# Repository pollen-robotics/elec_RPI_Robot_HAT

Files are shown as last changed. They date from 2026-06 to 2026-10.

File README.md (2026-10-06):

# "RPI_Robot_HAT" Electronic Board

> "RPI_Robot_HAT" is a raspberry pi HAT designed for small/medium size robots. It has an IMU, Dynamixel connectors and audio. Its size fits a Raspberry PI zero.

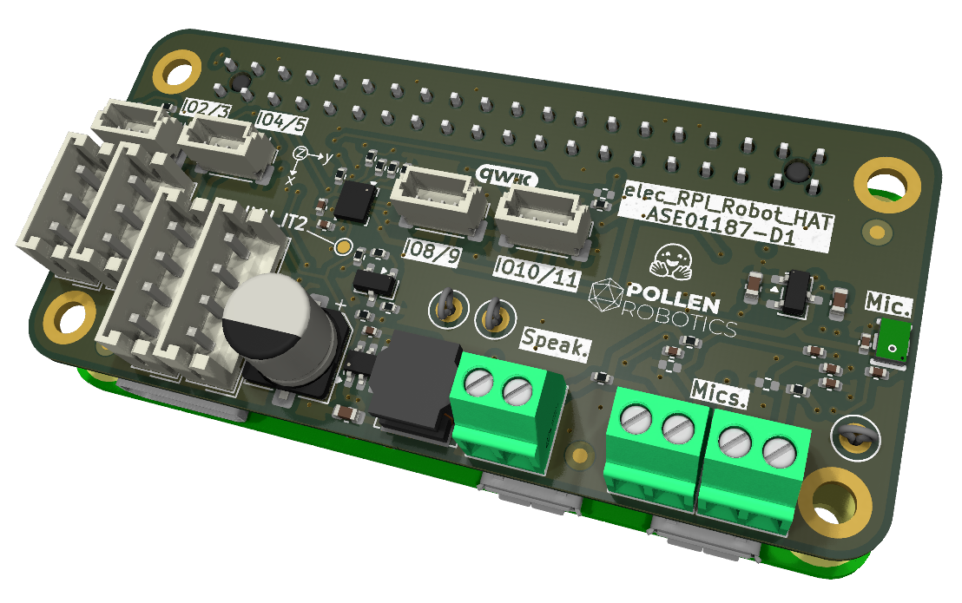
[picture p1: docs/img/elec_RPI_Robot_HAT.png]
3d view


The RPI_Robot_HAT gathers:

- **IMU** over I2C + data fusion
- **Dynamixel motor communication**: both TTL and 485 to drive Dynamixel/Feetech motor (requires cable adaptation)
- **in/out audio device** with an integrated mems microphone. Wago connectors allows connection of loudspeaker and extra microphone.
- **expension Qwiic connectors**, 1 mm/3V3. Please refer to the schematic for knowing which can be use on you raspberry pi.

The RPI_Robot_HAT can be power from 5 to 28V. It is designed to use of the motor connector as an power input.

## Releases
| Release | Date | Designer | Check  | Comments |
|---|---|---|---|---|
| A1 | 06/03/2026 | EB | SN | Initial drawing |
| B1 | 06/05/2026 | EB | SN |[fixed] Acc. is at 0x19 I2C address<br />[fixed] Soft reset of the audio DAC<br />[fixed] Ideal diode<br />[fixed] Know position of IMU<br />[update] Dynamixel_dir is based on Tx<br />[added] IMU can be disconnected<br />[added] IMU_IT is cabled<br />[added] Access to I2C0<br />[added] Switch off detection|
| C1 | 08/07/2026 | EB | SN | [fix] 3V3 on IO10/11<br />[fix] MOS direction of Ideal diode<br />[update] I2C3 is by default instead of reserved I2C|
| D1 | 06/10/2026 | EB | Claude | [update] IMU is now LSM6DSV16XTR<br />[update] RS485 Driver<br /> [update] screwable terminals for audio|

## Basically
 - Designed with KiCAD 9.

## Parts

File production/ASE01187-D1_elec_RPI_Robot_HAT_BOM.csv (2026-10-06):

Designator | Footprint | Quantity | Value | LCSC Part #
C1, C10, C2, C27, C29, C3, C31, C33, C35, C4, C40, C41, C42, C43, C6 | 0402 | 15 | 1u | C52923
C11, C14, C15, C16, C17, C18, C26, C28, C30, C32, C36, C38 | 0402 | 12 | 100n | C307331
C12, C13, C37, C5, C7 | 0603 | 5 | 10u | C1691
C19 | CP_Elec_6.3x7.7 | 1 | 10u 63V | C72488
C20 | 0402 | 1 | 100n 50V | C307331
C21, C22 | 0603 | 2 | 22u 6V3 | C84419
C23, C24, C39 | 0402 | 3 | 100n 6V3 | C1525
C25 | 0402 | 1 | DNP-100n
C34, C44 | 0402 | 2 | 10n | C15195
C45 | 0805 | 1 | 10u 35V | C33546007
C8, C9 | 0402 | 2 | 220n | C71693
D1 | SOT-323_SC-70 | 1 | BAT54W | C78606
D2 | D_SOD-123 | 1 | 3V3 Zener Diode | C19077392
D4 | D_SOD-323 | 1 | 5V1 | C151348
FB1 | 0402 | 1 | 1.3A 600R@100MHz | C76884
FB2, FB3 | 0402 | 2 | 2A - 120R@100MHz | C88970
G1 | Logo_qwiic_5mm | 1 | qwiic_Logo
H2 | Logo_HF_2025 | 1 | Logo HF 2025
J1, J2, J9 | CONN-TH_DB125-2.54-2P-GN | 3 | Screw term. | C918120
J11, J3 | JST_EH_B4B-EH-A_1x04_P2.50mm_Vertical | 2 | Dynamixel-4 | C160258
J13, J14 | JST_EH_B3B-EH-A_1x03_P2.50mm_Vertical | 2 | Dynamixel-3 | C160259
J4 | PinHeader_2x20_P2.54mm_Vertical_with_rasp_HAT_zero_SMD_connector | 1 | Female Header 2x20 SMD | C2685112
J5, J6, J7, J8 | JST_SH_BM04B-SRSS-TB_1x04-1MP_P1.00mm_Vertical | 4 | JST SH | C160390
L4 | L_Bourns_SRN6045TA | 1 | 6,8u 2A | C57254
MK1 | MIC-SMD_4P-L2.8-W1.9-P1.84-TL | 1 | Microphone_MEMS | C7587901
Q1 | SOT-23 | 1 | MMBT3906 | C727128
Q2 | TSOT-23 | 1 | N-Channel 5A | C22469448
R1, R12, R13, R2, R20, R21, R24, R26, R27, R29, R31, R32, R34, R35, R38, R39, R6 | 0402 | 17 | 10k | C25744
R10, R11 | 0402 | 2 | DNP-10k
R14, R15, R18, R19, R25, R3, R30, R4, R40, R5, R7, R9 | 0402 | 12 | 0R | C17168
R16, R17, R41 | 0402 | 3 | DNP-0R
R22, R23 | 0402 | 2 | 4k7 | C105871
R28 | 0402 | 1 | 20k | C25765
R33 | 0402 | 1 | 150R | C2909321
R36, R37 | 0402 | 2 | DNP-1M
R42 | 0402 | 1 | 1k | C105637
R8 | 0402 | 1 | 100R | C2906860
TH1 | 0603 | 1 | 100R thermistor | C913703
TP2, TP3, TP4 | TestPoint_Loop_D2.50mm_Drill1.0mm_LowProfile | 3 | TestPoint
TP5 | TestPoint_Pad_D1.0mm | 1 | TestPoint
U1 | SOIC-16_3.9x9.9mm_P1.27mm | 1 | PAM8406D | C86270
U10 | TSOT-23-6 | 1 | LM5050-1 | C473393
U12 | LGA-14_3x2.5mm_P0.5mm_LayoutBorder3x4y | 1 | LSM6DSV16XTR | C5267406
U2 | VQFN-32-1EP_5x5mm_P0.5mm_EP3.5x3.5mm | 1 | TLV320AIC3104IRHBR | C181753
U3 | SOT-23-3 | 1 | XC6206P182MR | C347373
U4 | TDFN-8_L3.0-W2.0-P0.50-BL-EP | 1 | DNP-CAT24C32HU4
U5 | SOT-23-5 | 1 | 74LVC1G08 | C7666
U6 | SOT-23-5 | 1 | SN74LVC1G125DBV | C23654
U7 | SOT-23-5 | 1 | SN74LVC1G126DBVR | C7834
U8 | DFN-8-1EP_3x3mm_P0.65mm_EP1.2x2.15mm | 1 | GM3088ENA | C49423279
U9 | TSOT-23-6 | 1 | AP63205 | C2071056
Y1 | Oscillator_SMD_Abracon_ASDMB-4Pin_2.5x2.0mm | 1 | 12 MHz | C7425459

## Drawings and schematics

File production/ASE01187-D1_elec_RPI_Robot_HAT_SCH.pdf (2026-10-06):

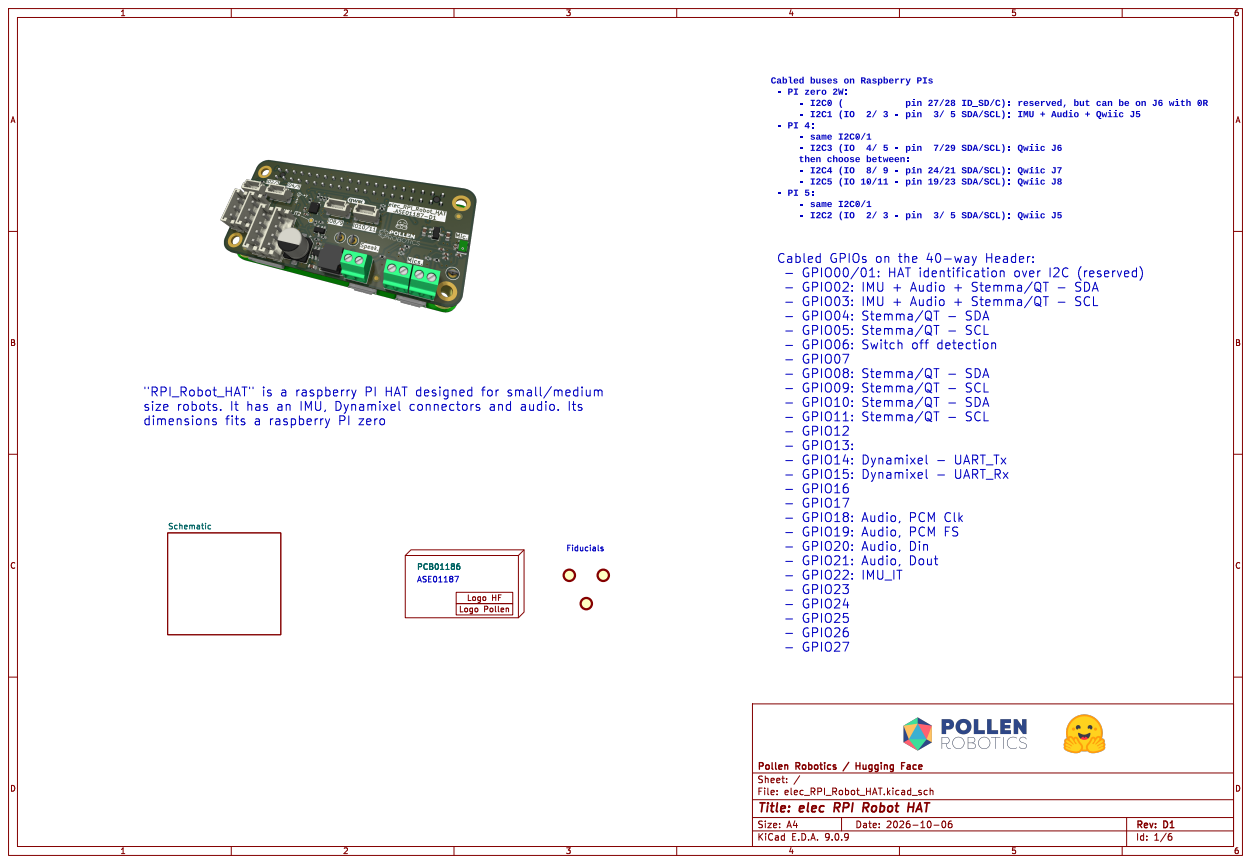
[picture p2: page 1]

Cabled buses on Raspberry PIs
- PI zero 2W:
- same I2C0/1
then choose between:
- I2C5 (IO 10/11 - pin 19/23 SDA/SCL): Qwiic J8

Id: 1/6 Title: elec RPI Robot HAT

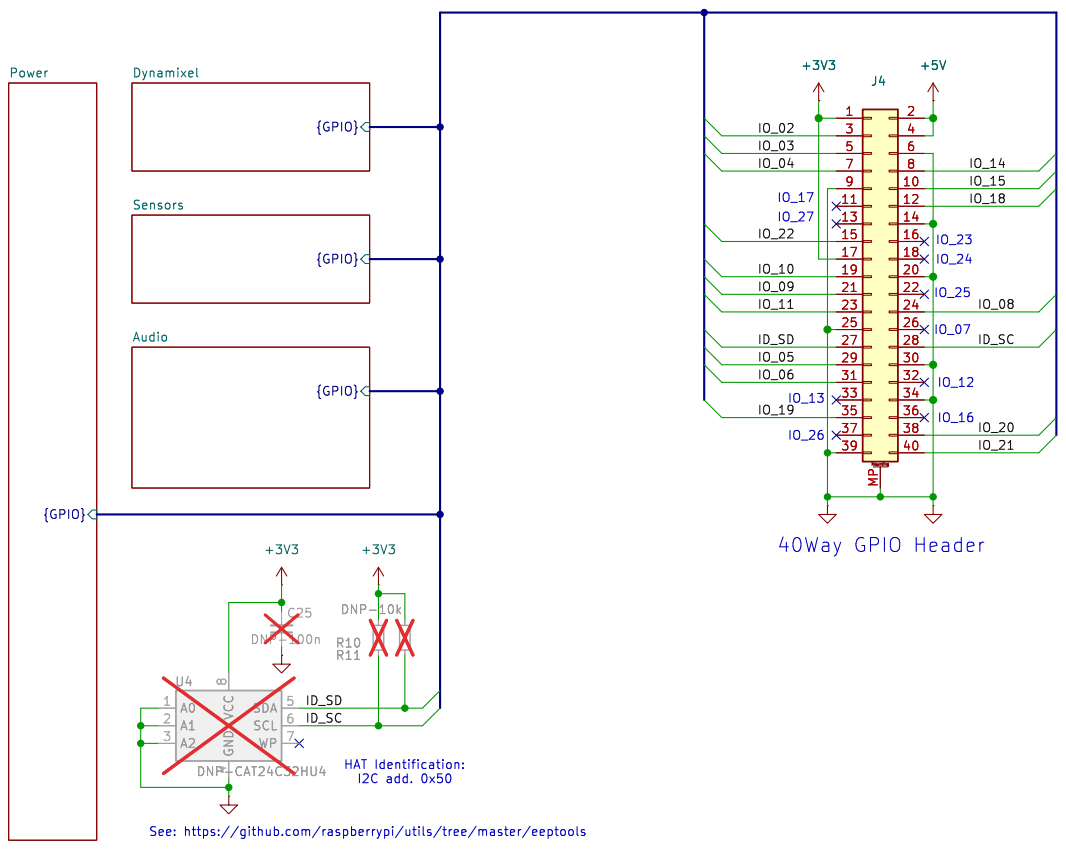
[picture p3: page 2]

I2C add. 0x50 See: https://github.com/raspberrypi/utils/tree/master/eeptools

Id: 2/6 Title: elec RPI Robot HAT

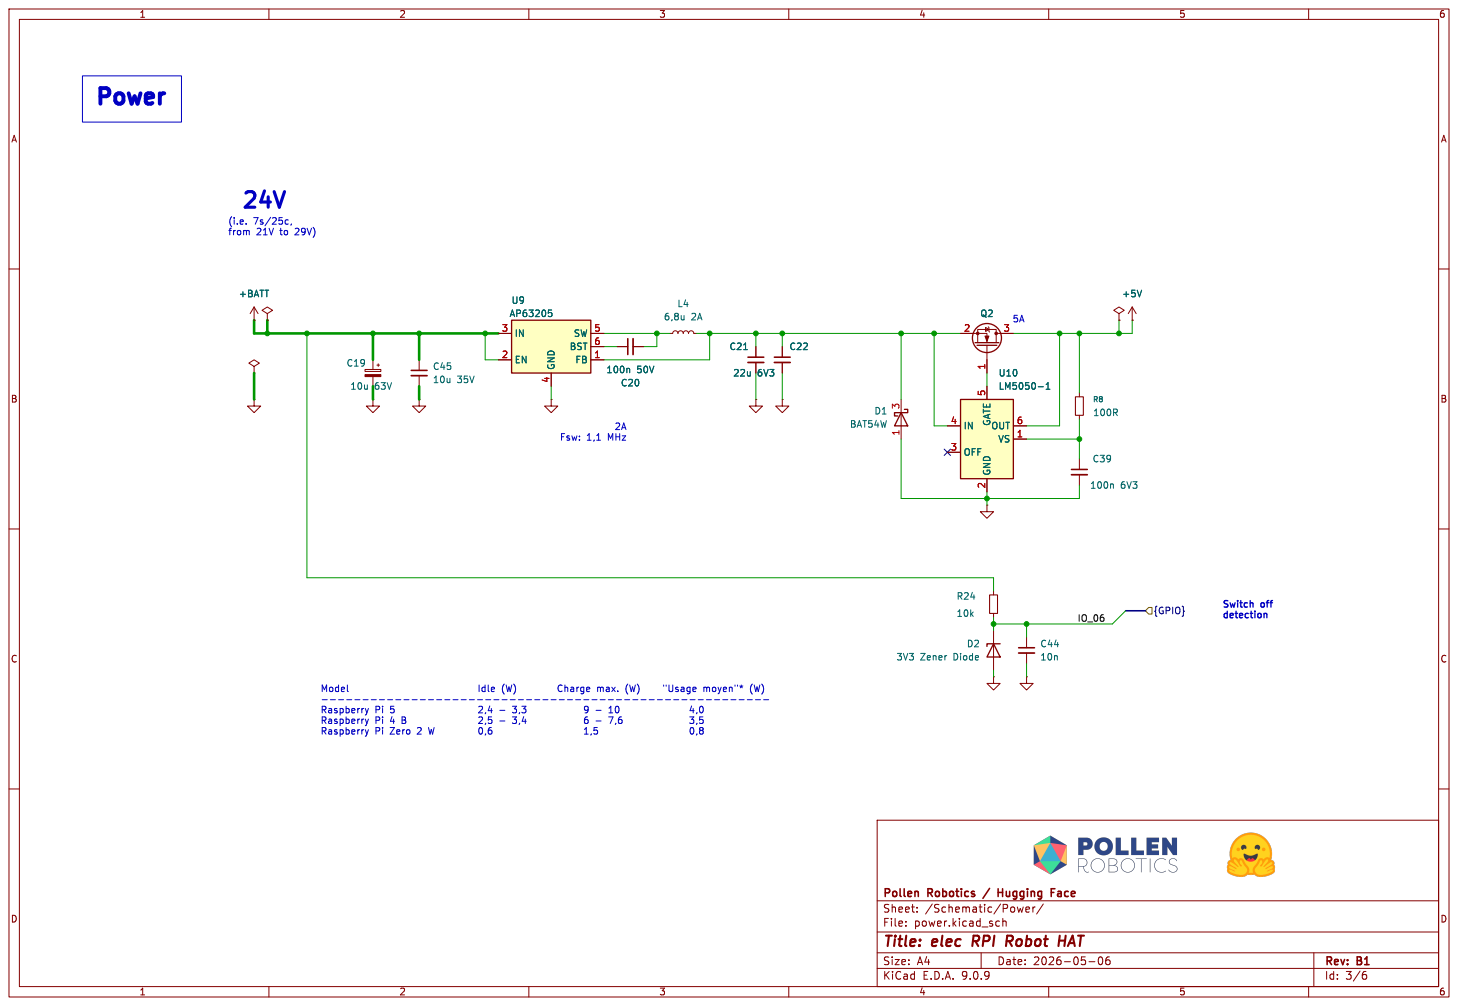
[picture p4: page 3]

4 SW 5 BST 6 FB 1 C22 +BATT

Id: 3/6 Title: elec RPI Robot HAT

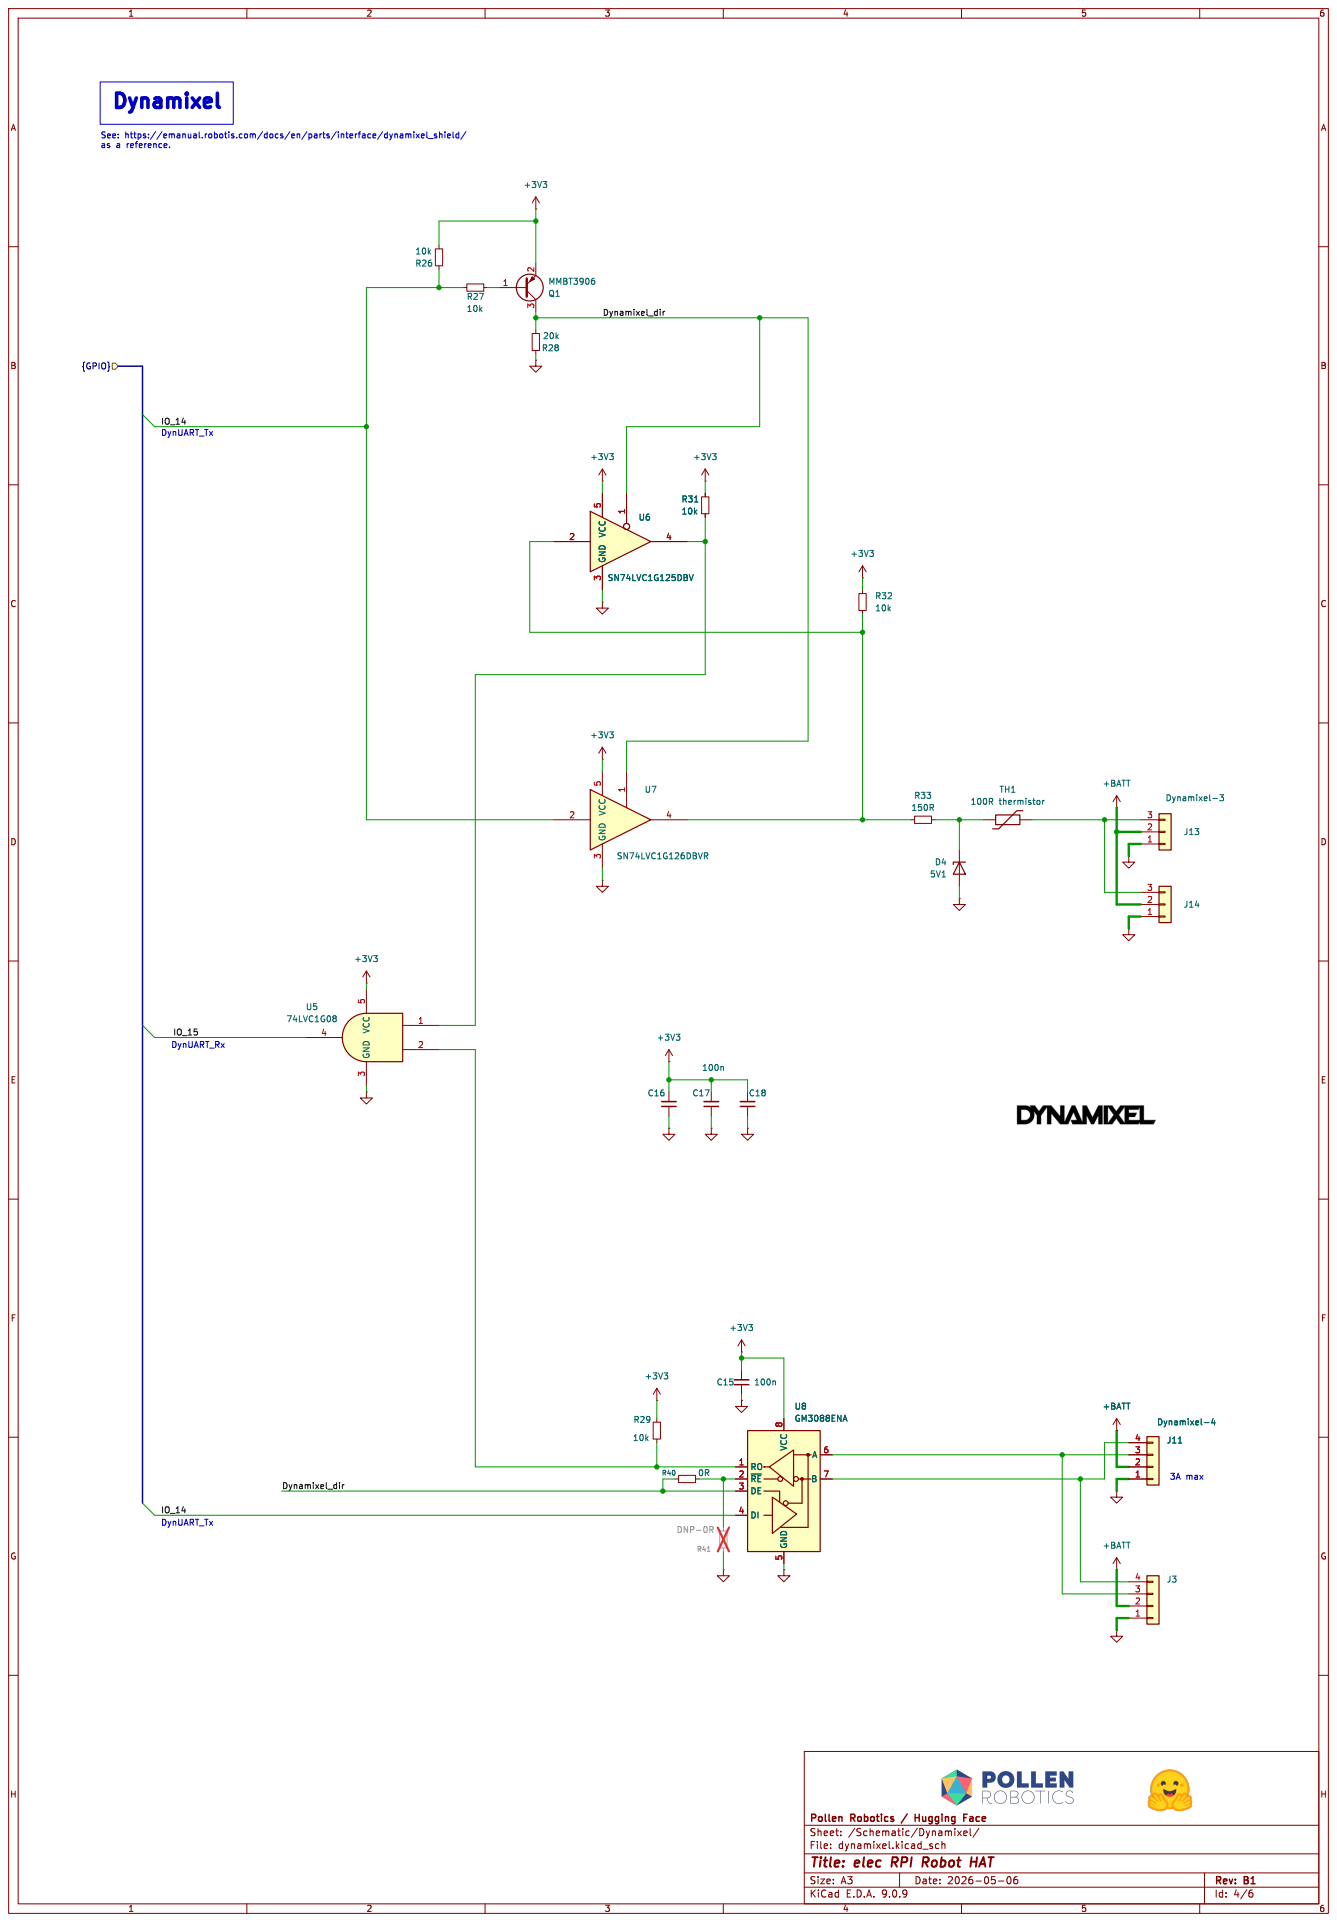
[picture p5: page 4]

IO_14 Dynamixel See: https://emanual.robotis.com/docs/en/parts/interface/dynamixel_shield/ as a reference.

Id: 4/6 Title: elec RPI Robot HAT

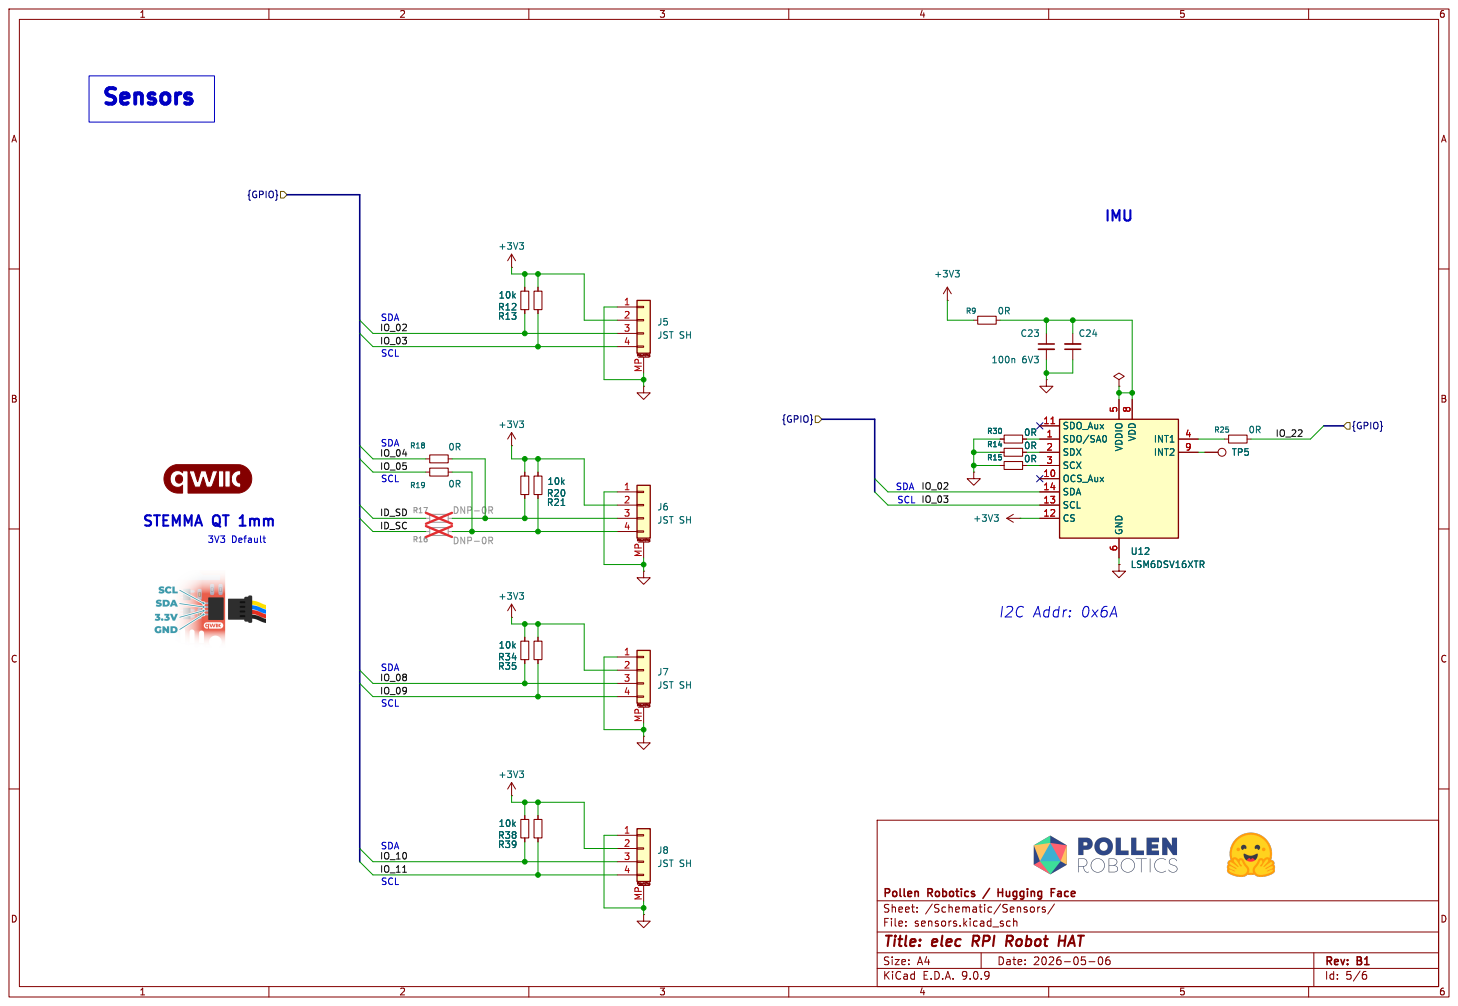
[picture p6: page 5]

Id: 5/6 Title: elec RPI Robot HAT

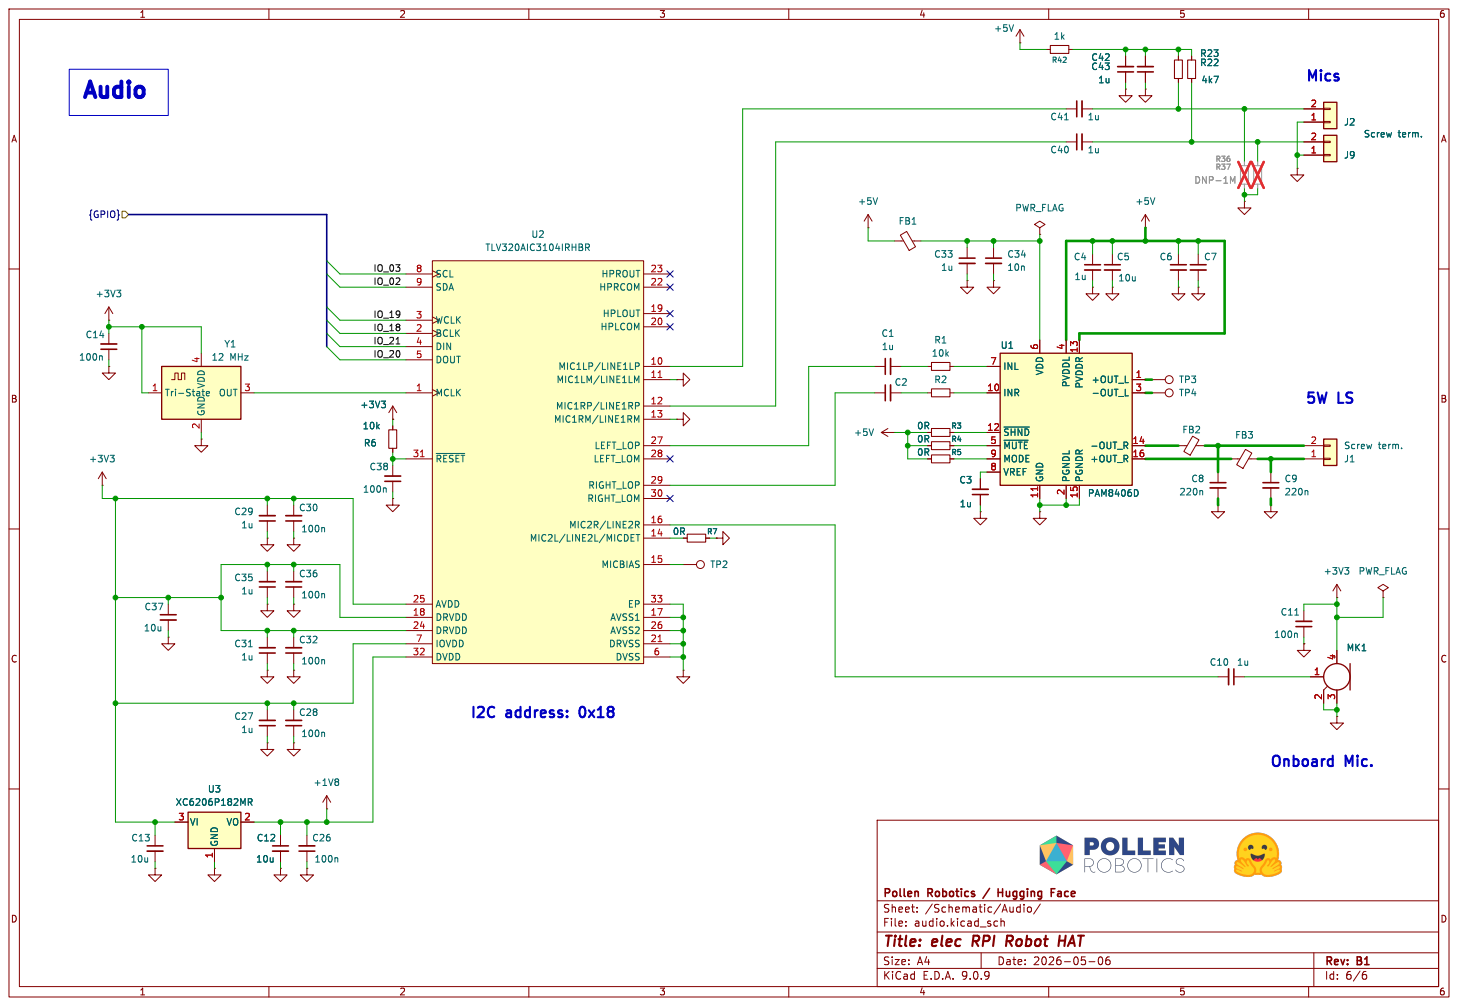
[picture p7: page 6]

Id: 6/6 Title: elec RPI Robot HAT

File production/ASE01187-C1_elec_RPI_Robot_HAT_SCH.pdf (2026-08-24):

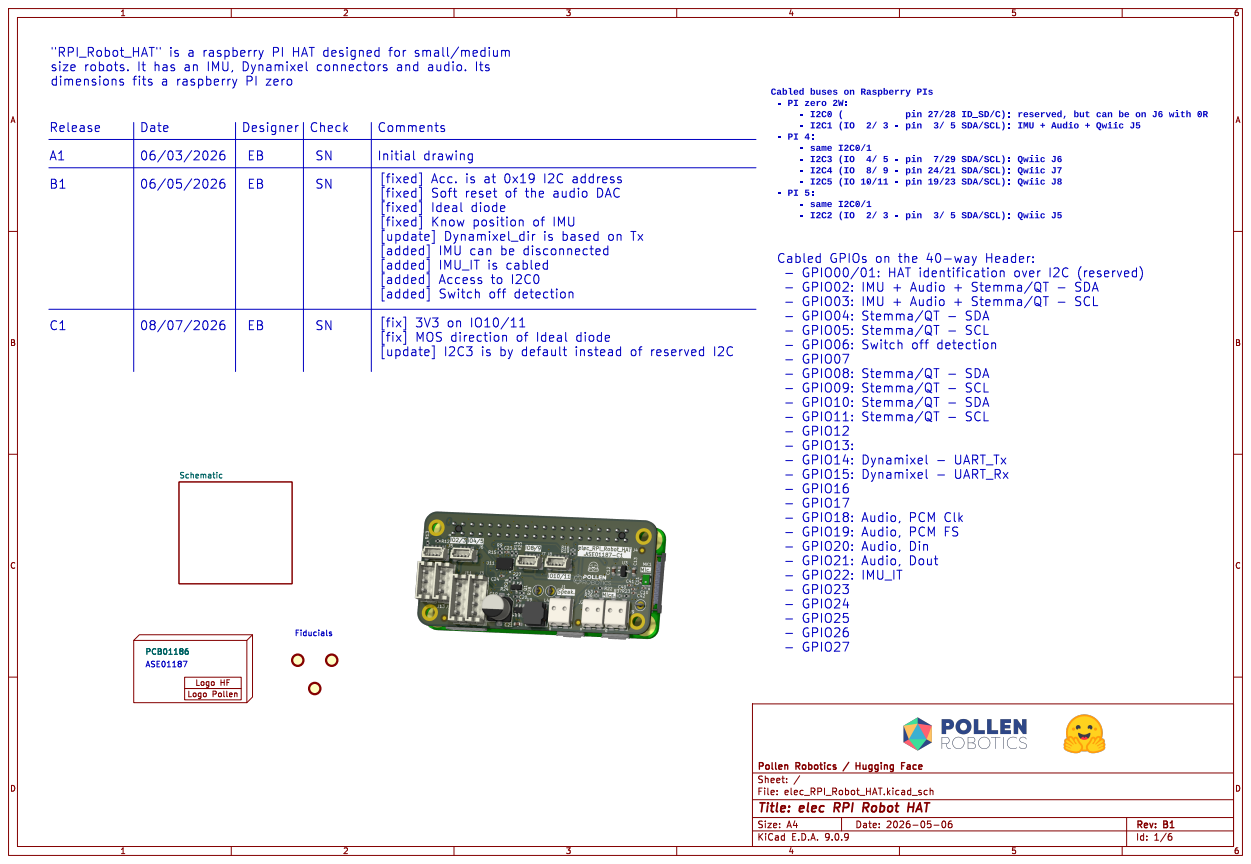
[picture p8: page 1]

Cabled buses on Raspberry PIs
- PI zero 2W:
- same I2C0/1
- I2C5 (IO 10/11 - pin 19/23 SDA/SCL): Qwiic J8

06/03/2026 | EB
06/05/2026 | EB

[added] IMU can be disconnected
[added] IMU_IT is cabled
[added] Access to I2C0
[added] Switch off detection

Id: 1/6 Title: elec RPI Robot HAT

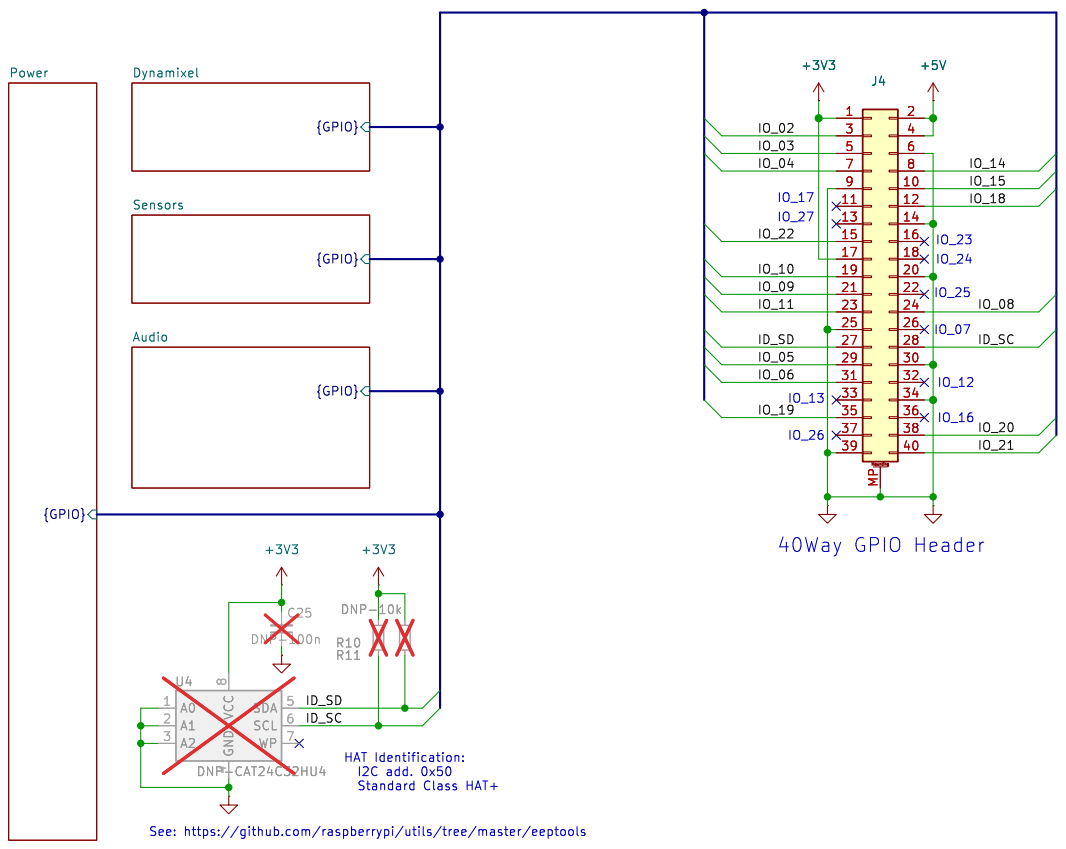
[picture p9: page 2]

IO_19 See: https://github.com/raspberrypi/utils/tree/master/eeptools HAT Identification:

I2C add. 0x50 Standard Class HAT+

Id: 2/6 Title: elec RPI Robot HAT

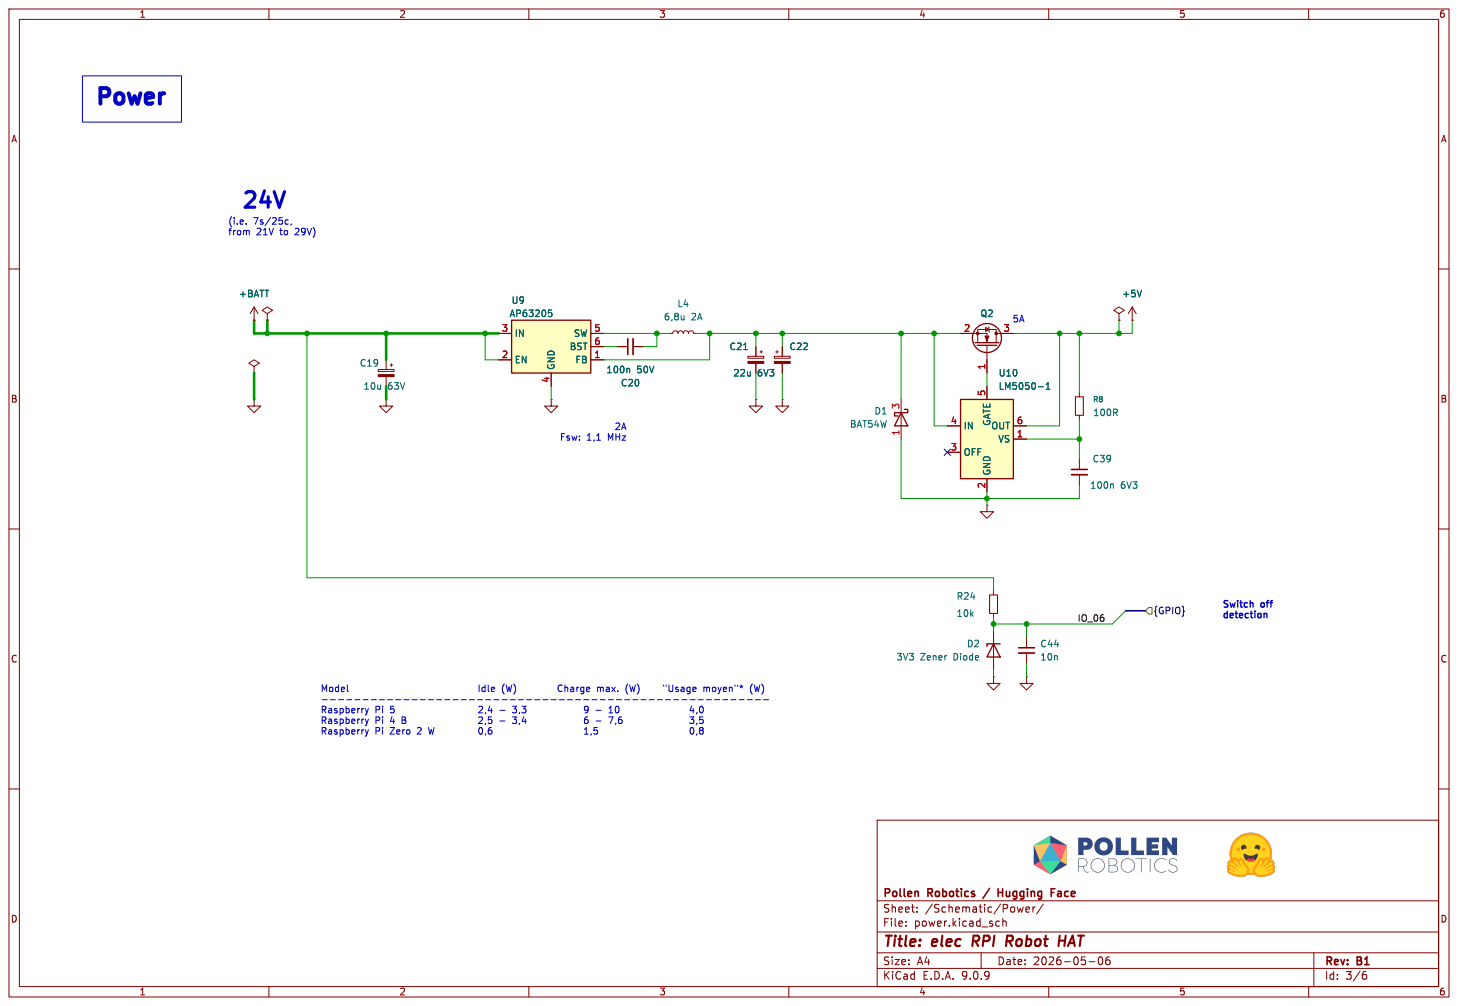
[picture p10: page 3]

Id: 3/6 Title: elec RPI Robot HAT

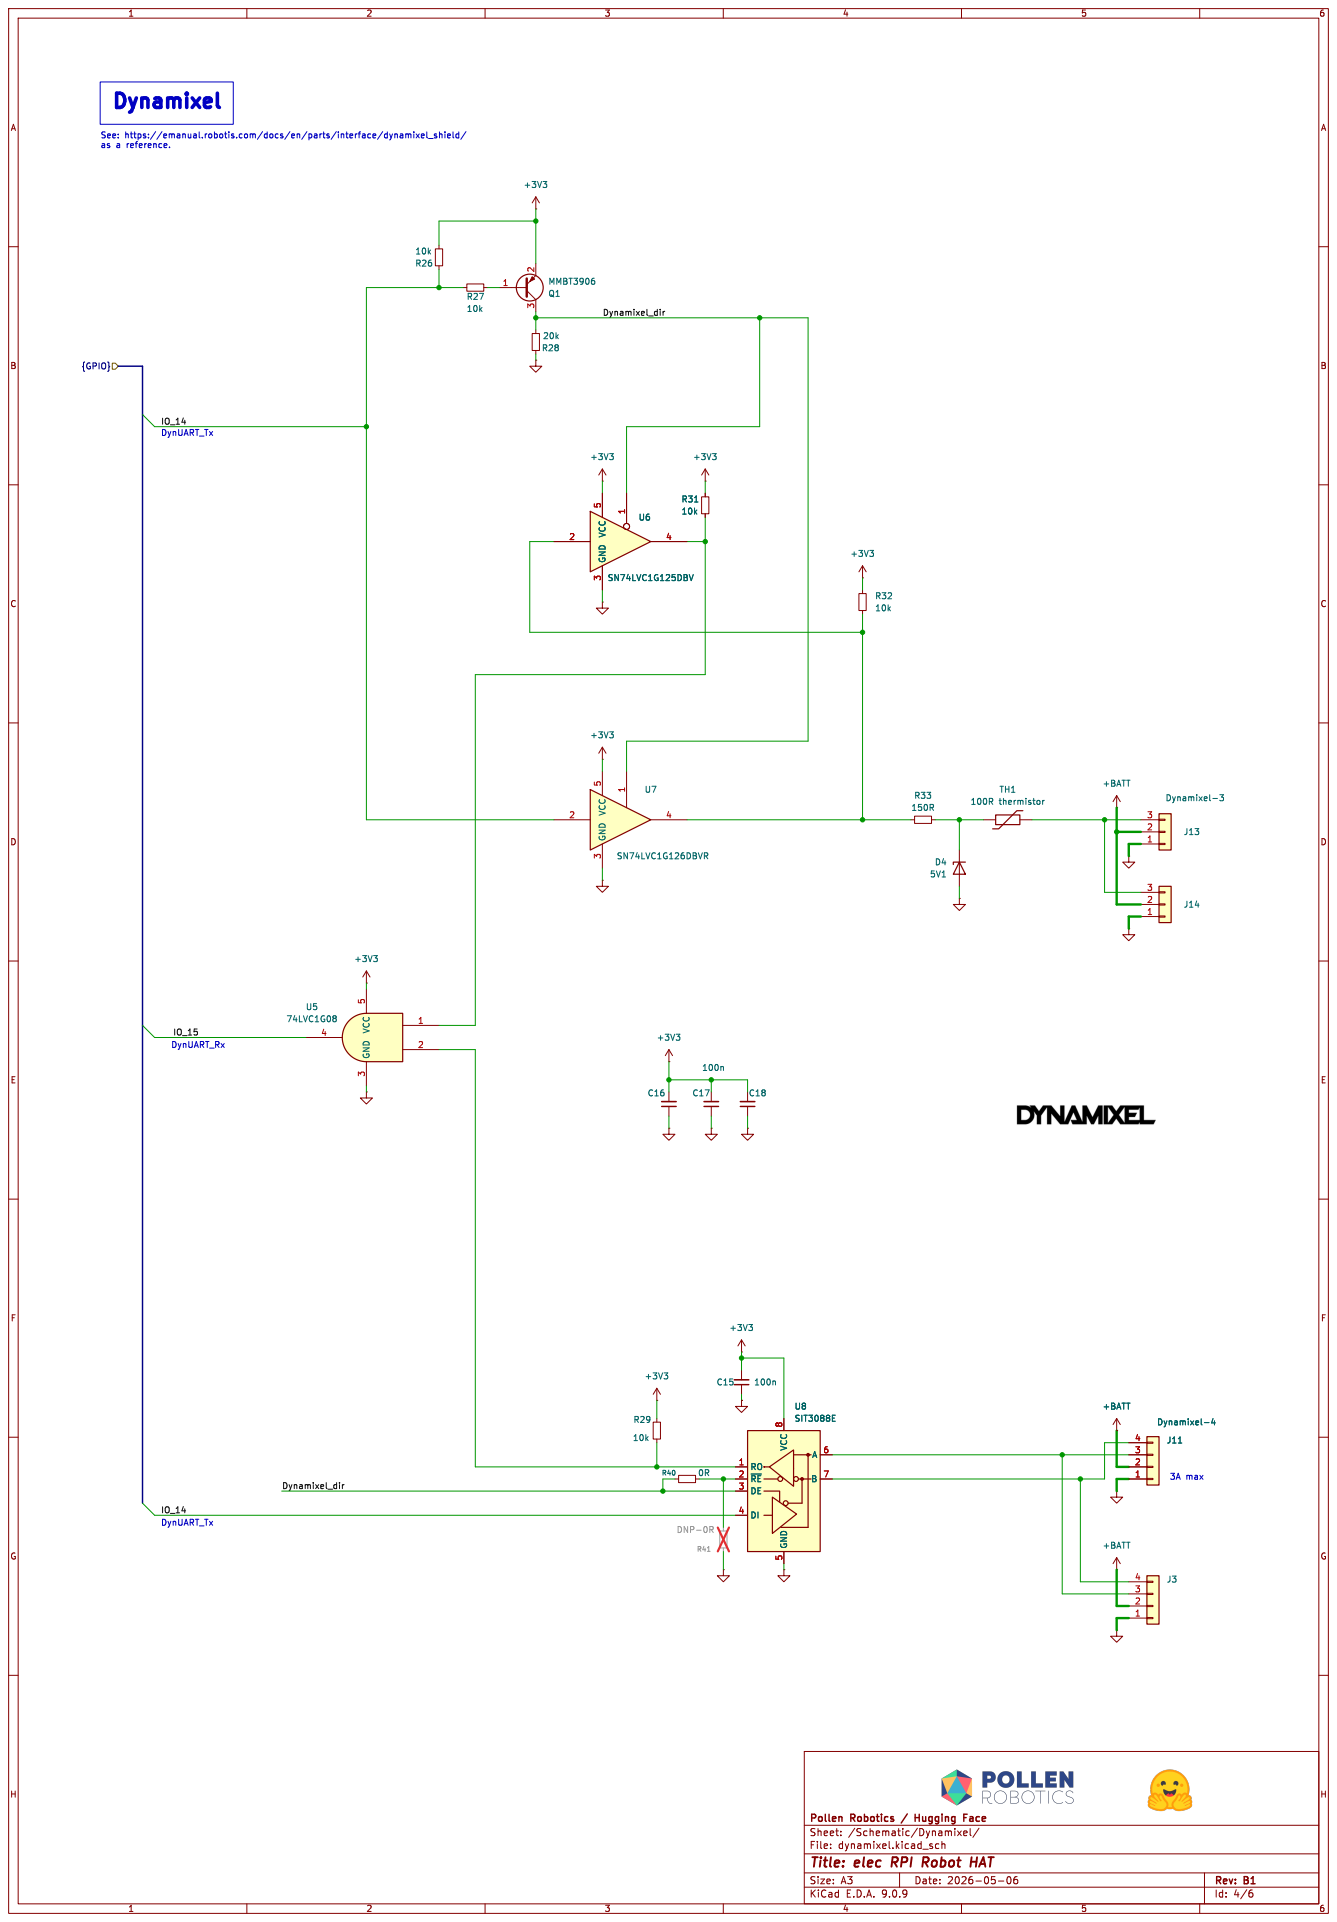
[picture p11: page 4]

IO_14 Dynamixel See: https://emanual.robotis.com/docs/en/parts/interface/dynamixel_shield/ as a reference.

Id: 4/6 Title: elec RPI Robot HAT

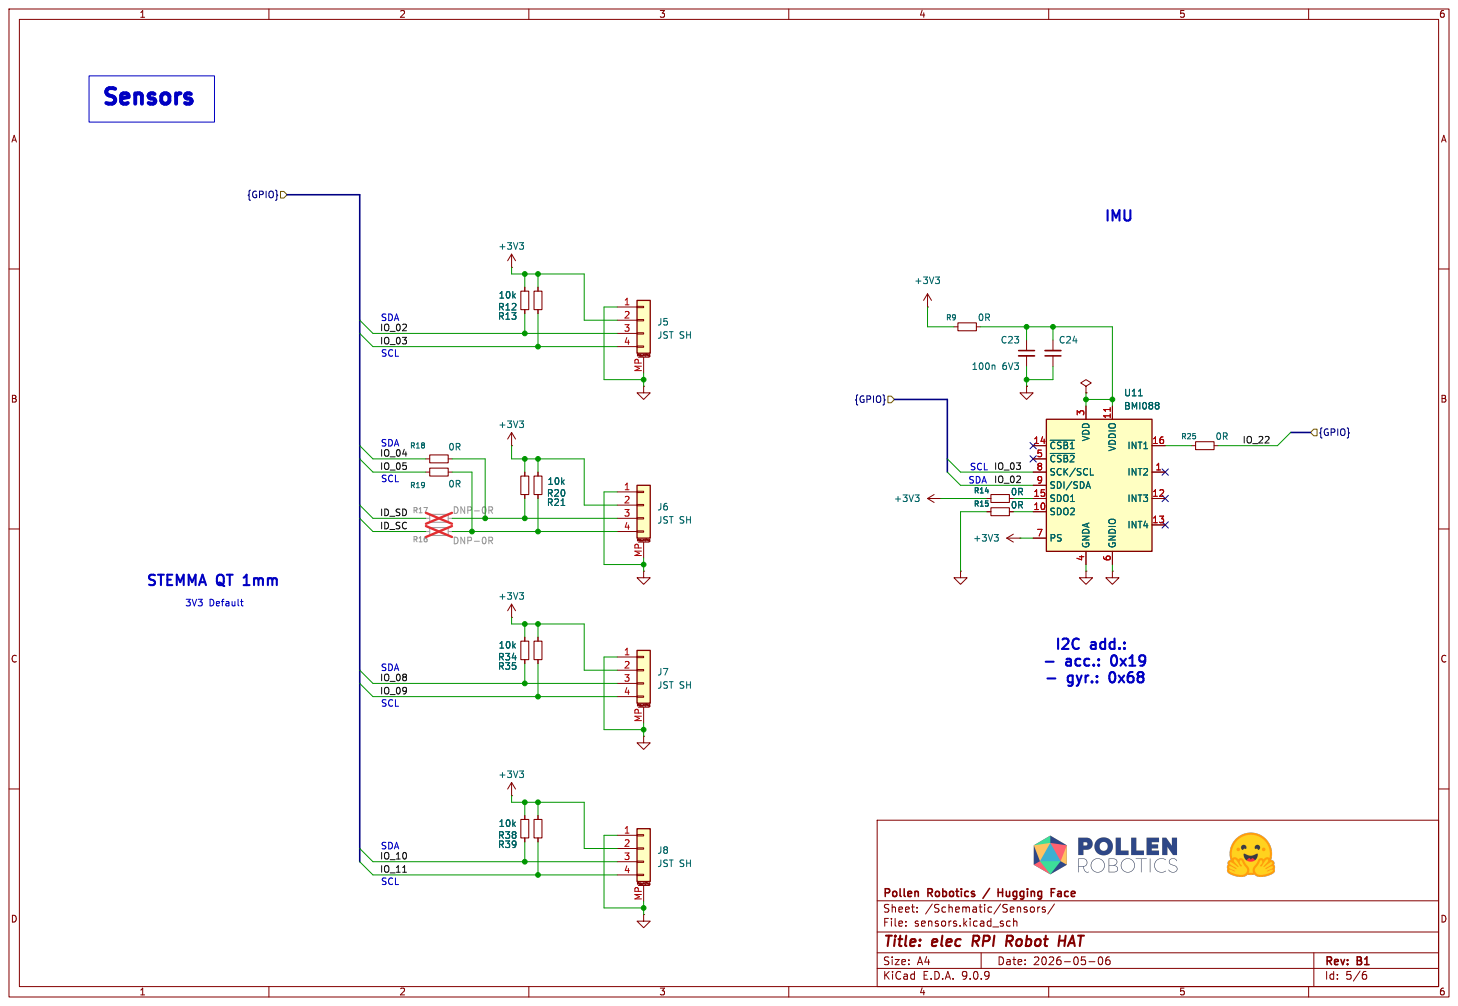
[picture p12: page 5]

Id: 5/6 Title: elec RPI Robot HAT

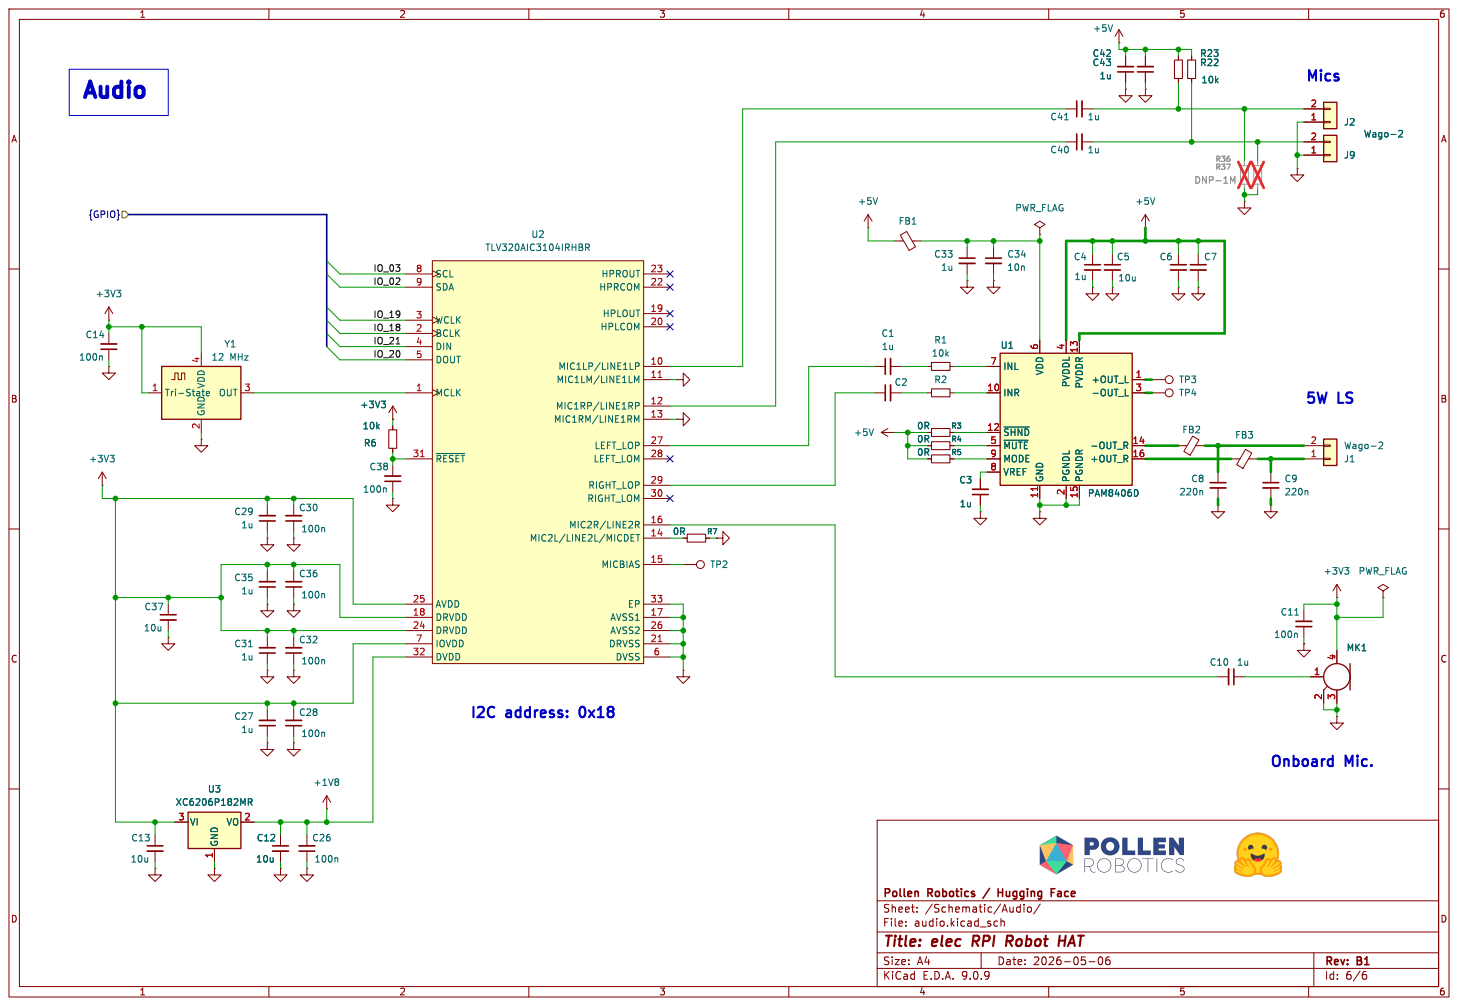
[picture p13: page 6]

Id: 6/6 Title: elec RPI Robot HAT

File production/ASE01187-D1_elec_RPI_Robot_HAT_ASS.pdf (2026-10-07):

1 | 2 | 3 | 4

A


Id: 1/1 Title: elec RPI Robot HAT

1 | 2 | 3 | 4

A


Id: 1/1 Title: elec RPI Robot HAT



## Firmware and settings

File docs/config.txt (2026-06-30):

# For more options and information see
# http://rptl.io/configtxt
# Some settings may impact device functionality. See link above for details

# Uncomment some or all of these to enable the optional hardware interfaces
dtparam=i2c_arm=on
dtparam=i2s=on
dtoverlay=tlv320aic3104
dtparam=spi=on

# Enable audio (loads snd_bcm2835)
dtparam=audio=off

# Additional overlays and parameters are documented
# /boot/firmware/overlays/README

# Automatically load overlays for detected cameras
camera_auto_detect=1

# Automatically load overlays for detected DSI displays
display_auto_detect=1

# Automatically load initramfs files, if found
auto_initramfs=1

# Enable DRM VC4 V3D driver
dtoverlay=vc4-kms-v3d
max_framebuffers=2

# Don't have the firmware create an initial video= setting in cmdline.txt.
# Use the kernel's default instead.
disable_fw_kms_setup=1

# Run in 64-bit mode
arm_64bit=1

# Disable compensation for displays with overscan
disable_overscan=1

# Run as fast as firmware / board allows
arm_boost=1

[cm4]
# Enable host mode on the 2711 built-in XHCI USB controller.
# This line should be removed if the legacy DWC2 controller is required
# (e.g. for USB device mode) or if USB support is not required.
otg_mode=1

[cm5]
dtoverlay=dwc2,dr_mode=host

[pi02]
dtparam=i2c_arm_baudrate=100000

[all]
enable_uart=1

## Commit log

2026-02-24 [init] First commit
    [dynamixel.kicad_sch, elec_RPI_Robot_HAT.kicad_pcb, elec_RPI_Robot_HAT.kicad_sch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]
2026-02-24 [added] datasheets
    [elec_RPI_Robot_HAT.kicad_pcb, elec_RPI_Robot_HAT.kicad_sch]
2026-03-02 [update] Thinking about audio.
    [elec_RPI_Robot_HAT.kicad_pcb, elec_RPI_Robot_HAT.kicad_sch, power.kicad_sch]
2026-03-03 [update] All schematic up.
    [audio.kicad_sch, elec_RPI_Robot_HAT.kicad_pcb, elec_RPI_Robot_HAT.kicad_sch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]
2026-03-04 [update] Schematic completed.
    [audio.kicad_sch, dynamixel.kicad_sch, elec_RPI_Robot_HAT.kicad_pcb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]
2026-03-04 [update] Started routing. Started routing.# Veuillez saisir le message de validation pour vos modifications. Les lignes
    [elec_RPI_Robot_HAT.kicad_pcb, elec_RPI_Robot_HAT.kicad_sch]
2026-03-04 [update] Ongoing routing.
    [elec_RPI_Robot_HAT.kicad_pcb]
2026-03-05 [update] BU before changing the 40-pin GPIO
    [audio.kicad_sch, elec_RPI_Robot_HAT.kicad_pcb, elec_RPI_Robot_HAT.kicad_sch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]
2026-03-05 [update] Routing...
    [elec_RPI_Robot_HAT.kicad_pcb, elec_RPI_Robot_HAT.kicad_sch]
2026-03-06 [update] Fully routed, need DRC!
    [audio.kicad_sch, dynamixel.kicad_sch, elec_RPI_Robot_HAT.kicad_pcb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]
2026-03-06 [update] Just figure out the 40-pin GPIO conn. is inverted :-/
    [audio.kicad_sch, elec_RPI_Robot_HAT.kicad_pcb, elec_RPI_Robot_HAT.kicad_sch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]
2026-03-06 [update] Positionning after flipping.
    [audio.kicad_sch, elec_RPI_Robot_HAT.kicad_pcb]
2026-03-06 [update] Now re-routed.
    [elec_RPI_Robot_HAT.kicad_pcb]
2026-03-09 [update] Routed, ERC OK, RC1
    [elec_RPI_Robot_HAT.kicad_pcb, power.kicad_sch]
2026-03-09 [update] +image
    [elec_RPI_Robot_HAT.kicad_pcb, elec_RPI_Robot_HAT.kicad_sch]
2026-03-09 [update] Release A1, production of 15 boards by JLCPCB
    [audio.kicad_sch, dynamixel.kicad_sch, elec_RPI_Robot_HAT.kicad_pcb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]
2026-04-07 [added] Docs
    [elec_RPI_Robot_HAT.kicad_pcb, elec_RPI_Robot_HAT.kicad_sch]
2026-04-17 [update] On-going corrections for B1
    [audio.kicad_sch, dynamixel.kicad_sch, elec_RPI_Robot_HAT.kicad_pcb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]
2026-04-21 [update] 485 fix for elec_tartine
    [elec_RPI_Robot_HAT.kicad_sch]
2026-04-28 [update] B1-RC1, DRC OK on sch/pcb
    [audio.kicad_sch, dynamixel.kicad_sch, elec_RPI_Robot_HAT.kicad_pcb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]
2026-04-28 [update] RS485 trans. updated because of availability
    [dynamixel.kicad_sch, elec_RPI_Robot_HAT.kicad_pcb]
2026-05-03 [update] Ongoing corr.
    [elec_RPI_Robot_HAT.kicad_pcb]
2026-06-20 [errors] Missing 3v3 on J8/R38/R39
    [elec_RPI_Robot_HAT.kicad_sch]
2026-06-20 [update] JLC order
    [audio.kicad_sch, elec_RPI_Robot_HAT.kicad_pcb, elec_RPI_Robot_HAT.kicad_sch]
2026-06-30 [release] B1 (has been produced qtty 125 by JLCPCB)
    [audio.kicad_sch, bom_B1.csv, config.txt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]
2026-07-08 [fix] Default I2C 0R
    [dynamixel.kicad_sch, sensors.kicad_sch]
2026-07-08 [update] Release C1 (for Grabette), now qtty 20 @JLCPCB
    [elec_RPI_Robot_HAT.kicad_pcb, elec_RPI_Robot_HAT.kicad_sch, power.kicad_sch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]
2026-08-24 [added] Production file for C1
    [ASE01187-C1_elec_RPI_Robot_HAT_BOM.csv, elec_RPI_Robot_HAT.kicad_sch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]
2026-09-14 [update] todo
    [elec_RPI_Robot_HAT.kicad_sch]
2026-10-06 [update] JLC-ready, time for Claude review
    [audio.kicad_sch, dynamixel.kicad_sch, elec_RPI_Robot_HAT.kicad_pcb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]
2026-10-06 [update] post-Claude corrections
    [ASE01187-C1_elec_RPI_Robot_HAT_BOM.csv, ASE01187-D1_elec_RPI_Robot_HAT_BOM.csv, audio.kicad_sch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]
2026-10-07 [update] Now ordered in qtty 100 at JLCPCB. Updated Assembly document.
    [elec_RPI_Robot_HAT.kicad_pcb]
